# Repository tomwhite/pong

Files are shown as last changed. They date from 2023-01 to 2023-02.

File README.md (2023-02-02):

# Pong

An Arduino port of [pypaddle](https://github.com/arpruss/pypaddle), which is "a paddle ball bouncing game very similar to Pong".

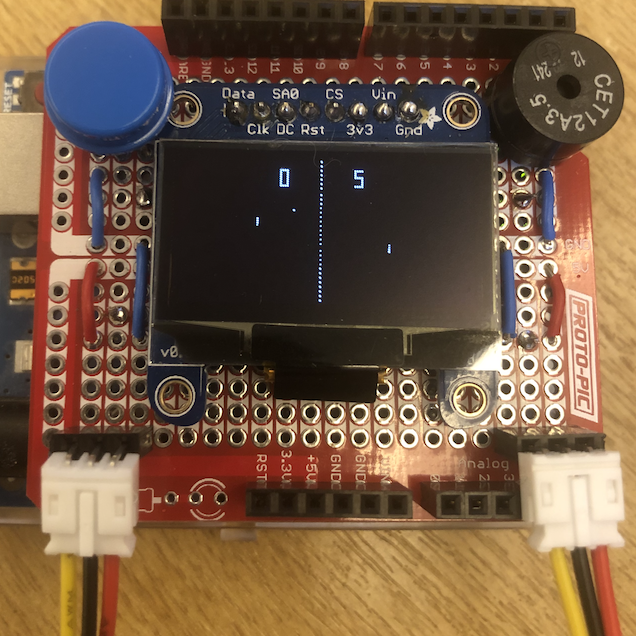
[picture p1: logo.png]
Pong OLED


This version can use an OLED display, or a TV via the TVout library.

## Background

I was inspired to build an Arduino OLED version of Pong after reading [this post by Benjamin Woehrl](https://medium.com/@ruction/arduino-pong-i2c-oled-128x64-bd4185970b50).

After I built it, I came across this [project for building paddle game controllers](https://www.instructables.com/USB-Paddle-Game-Controller/). The author, arpruss, wrote a Python (pygame) implementation of Pong that used the controllers he'd made, and which went to great lengths to reproduce the timings and behaviour of the original. His source for these details included an incredibly in-depth [circuit analysis of the original Atari Pong game](http://www.pong-story.com/LAWN_TENNIS.pdf), by Dr. H. Holden. Before I saw this I hadn't realised that Pong was implemented using TTL chips, rather than a microprocessor.

The code here is a port of the pypaddle pygame implementation to C++ suitable for running on an Arduino. The original pypaddle code is written so that it can scale to different screen sizes, and the timing code is independent of the speed of the update loop, which means that the experience of playing it on a regular machine using pypaddle, or the port on an Arduino with an OLED screen or a TV is virtually indistinguishable.

I also stumbled across this amazing [electronic circuit simulator in Javascript](http://falstad.com/circuit/). I encourage you to have a look at all the examples, but the [Pong simulation](https://www.falstad.com/pong/) is something else. You can even [play a limited form of the game in the browser](https://www.falstad.com/pong/vonly.html)!

## OLED version

### Parts list

- 1x Arduino Uno and power supply
- 1x Mini breadboard
- 1x Adafruit Monochrome 1.3" 128x64 OLED graphic display
- 2x Rotary potentiometer 10kΩ (e.g. Pimoroni NH00N2CB10K)
- 2x Knob
- 1x Push button
- 1x Buzzer - 5V
- 2x JST-PH Jumper Assembly (3 Wire)
- Jumper wires
- Solid core wire
- Solder
- (Optional) 1x Proto shield or Breadboard shield (e.g. Proto-PIC PPBBSFAR3)

### Wiring

Here's the first version I built on a breadboard:

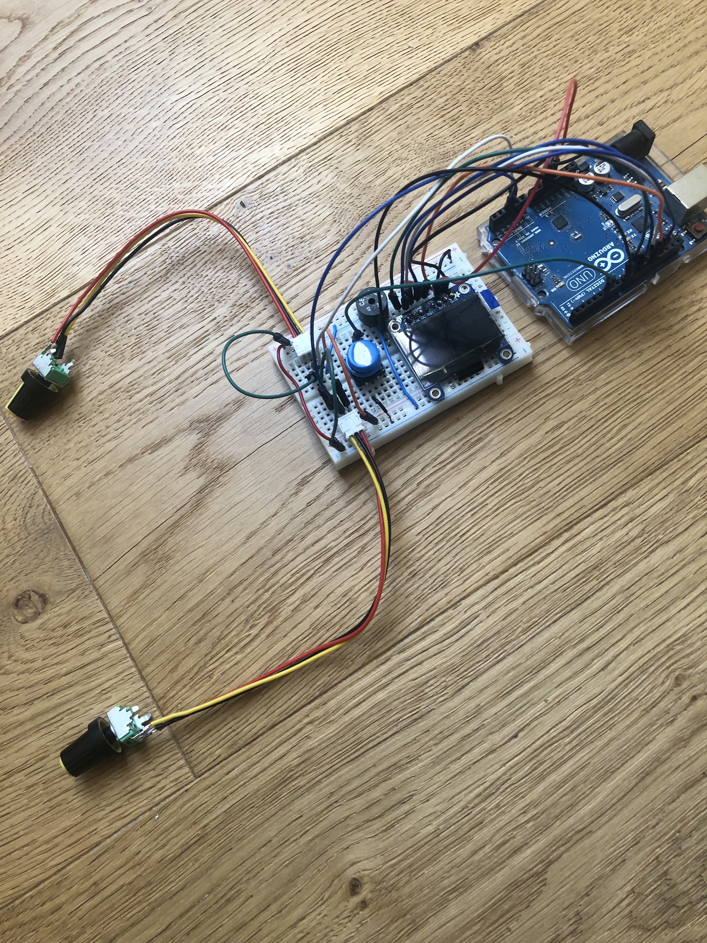
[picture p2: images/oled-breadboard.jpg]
Pong OLED on a breadboard


The controllers are just potentiometers soldered to a JST-PH connector to make it easy to detach them from the breadboard or proto shield.

I used the SPI interface to the OLED, this is explained in detail in the [Adafruit documentation](https://learn.adafruit.com/monochrome-oled-breakouts/wiring-128x64-oleds).

Here's the breadboard wiring diagram:

<!-- ![Breadboard wiring diagram for Pong OLED](images/pong-oled_bb.png | width=500) -->
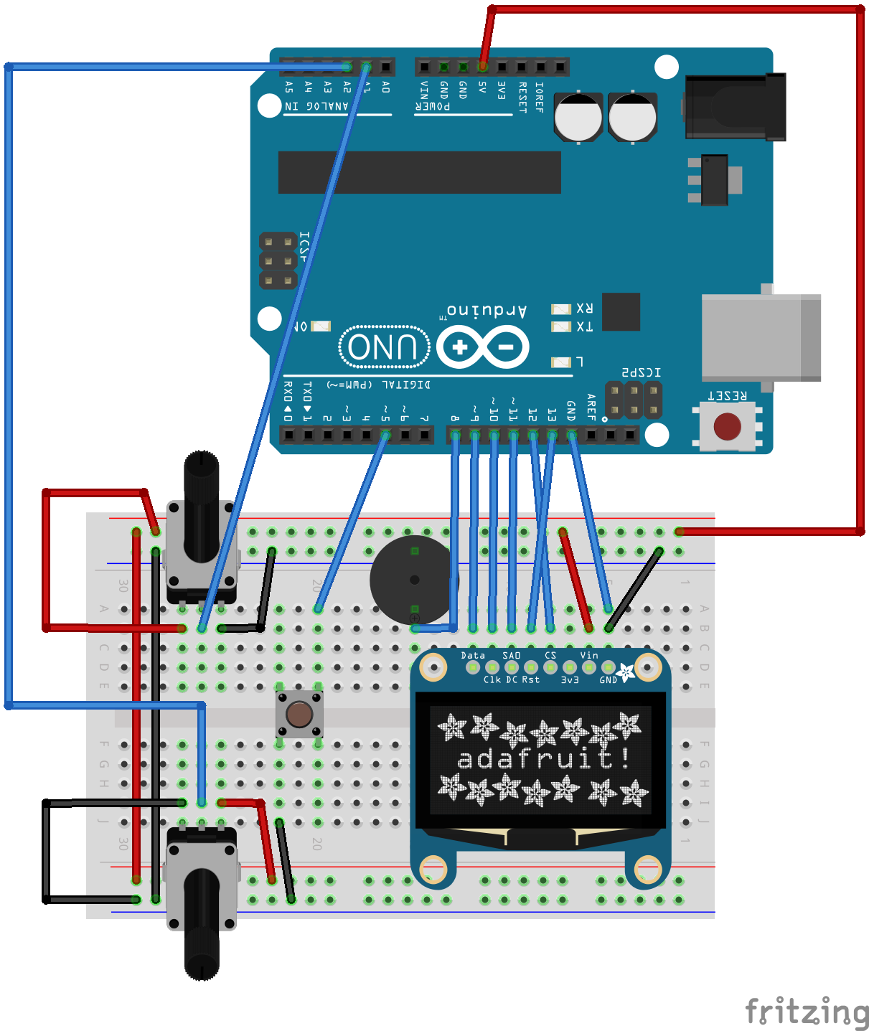
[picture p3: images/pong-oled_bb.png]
Breadboard wiring diagram for Pong OLED


I then transferred the circuit to a proto shield. This is much more compact, and makes it easier to play since the controllers are now either side of the screen.

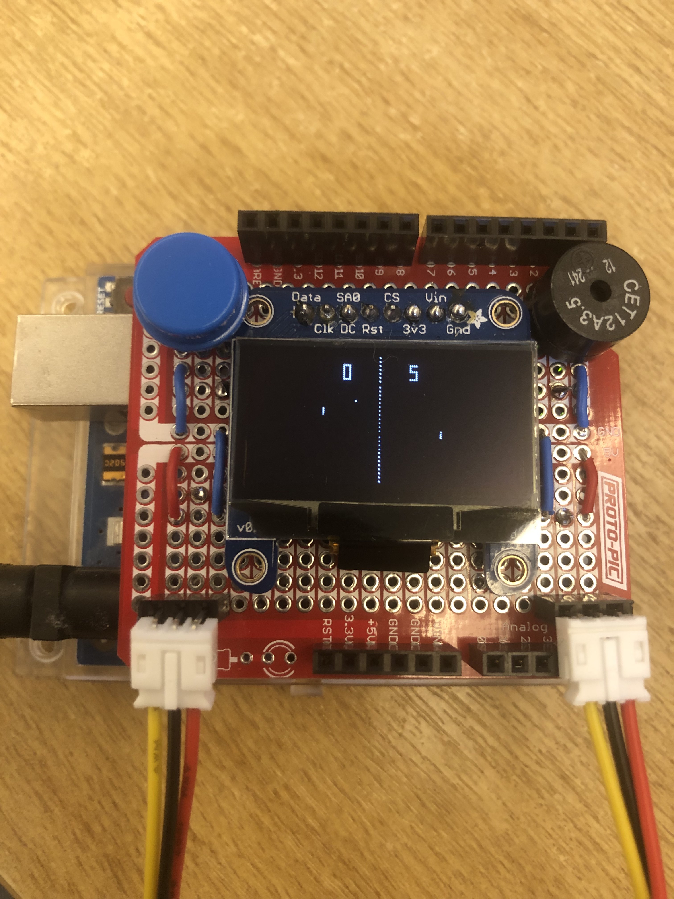
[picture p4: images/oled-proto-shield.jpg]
Pong OLED on a proto shield


## TVout version

After I got the OLED version working, I updated the code so it could work using the TVout library. Since the picture stored in memory is 128x96 pixels (black or white), that's 12,288 bits, or 1,536 bytes. The Arduino Uno only has 2K of SRAM, so that's less than half a kilobyte left for the game itself. To get it to fit I had to use program memory for the digit segment data. (The [Arduino Memory Guide](https://docs.arduino.cc/learn/programming/memory-guide) is well worth a read to understand the different types of memory an Arduino has.)

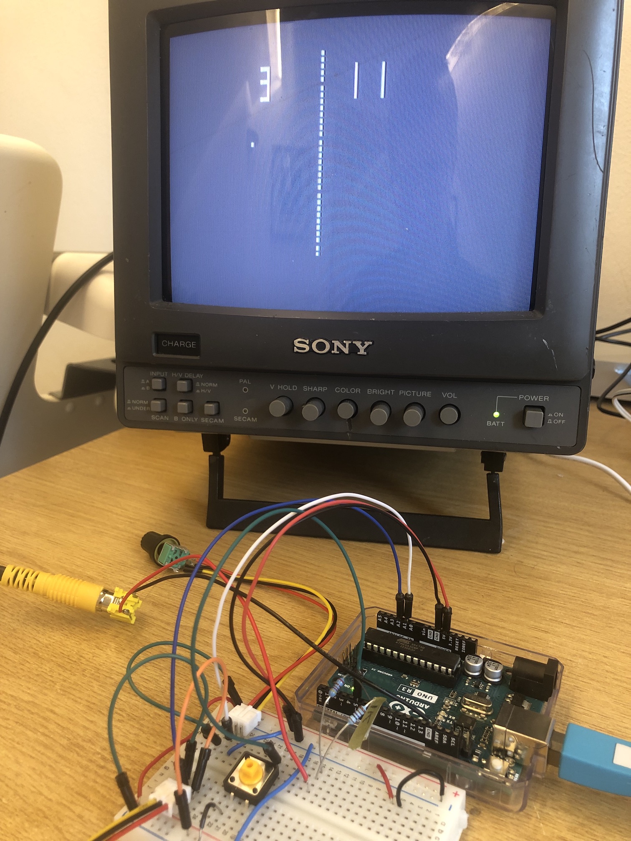
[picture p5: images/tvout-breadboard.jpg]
Pong TVout on a breadboard


Amazingly the TVout library just needs a couple of resistors and a connector to hook up to a TV.

### Parts list

The parts list is not very different from the OLED version. Instead of the OLED graphic display I used a TV with a composite video input, and the following parts.

- 1x Resistor, 470Ω
- 1x Resistor, 1kΩ
- 1x RCA/Phono jack socket
- 1x Composite video cable

For the RCA socket I de-soldered one from a very old broken Raspberry Pi board I had lying around.

### Wiring

Here's the breadboard wiring diagram:

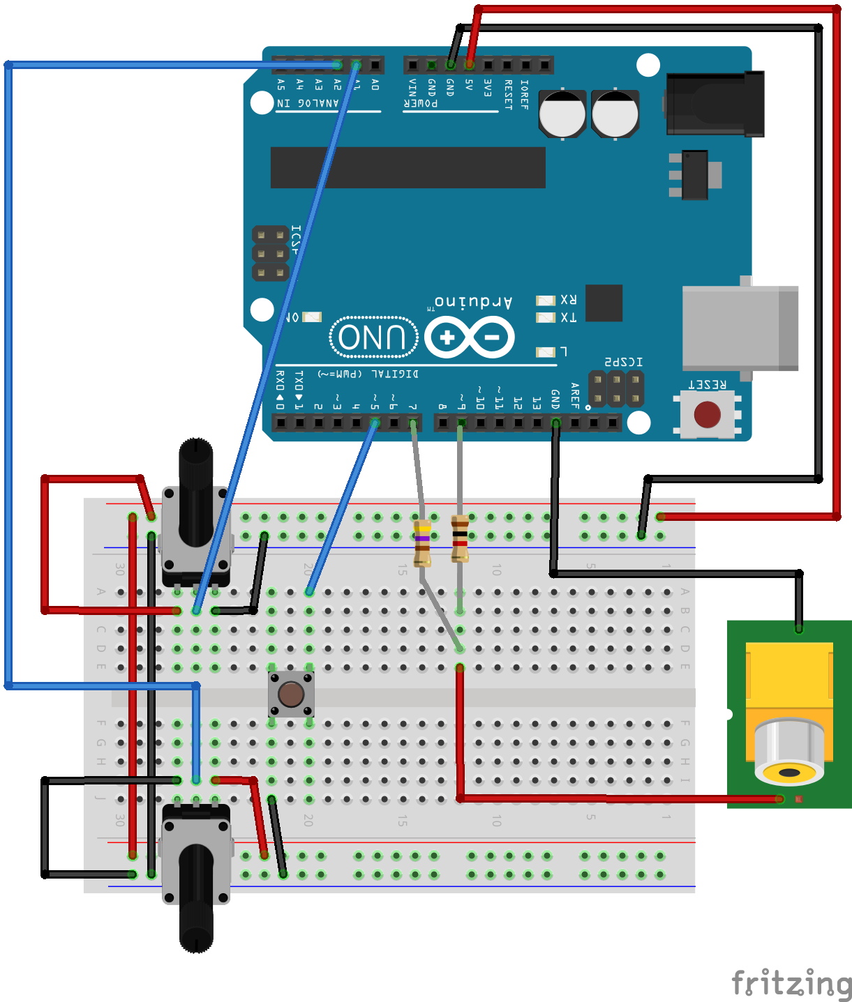
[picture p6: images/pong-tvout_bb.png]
Breadboard wiring diagram for Pong TVout


## Code

Both the OLED and TVout version use the same codebase. You just need to change a `#define` at the top to compile for one or the other.

[pong.ino](pong.ino)

I used version 2.3.1 of the Adafruit SSD1306 library for the OLED display.

There are several versions and forks of the TVout library. I manually installed the one from https://github.com/nootropicdesign/arduino-tvout, from the people behind the wonderful [Hackvision](https://nootropicdesign.com/hackvision/) (which, BTW, also has an implementation of Pong).

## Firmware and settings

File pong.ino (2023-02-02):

/*

  An Arduino port of pypaddle, which is "a paddle ball bouncing game very similar to Pong".

  See https://github.com/arpruss/pypaddle

  This version can use an OLED display, or a TV via the TVout library.

  Further details, including wiring, at https://github.com/tomwhite/pong.

*/

// Compile for an OLED disply by default. To use TVout, comment out the following line.
#define OLED 1

#define CONTROLLER_1 1
#define CONTROLLER_2 2
#define BUTTON_PIN 5
#define SOUND_PIN 8

#ifdef OLED

#include <Adafruit_SSD1306.h>      // Driver library for 'monochrome' 128x64 and 128x32 OLEDs

#define SCREEN_WIDTH 128 // OLED display width, in pixels
#define SCREEN_HEIGHT 64 // OLED display height, in pixels

// Declaration for SSD1306 display connected using software SPI (default case):
#define OLED_MOSI   9
#define OLED_CLK   10
#define OLED_DC    11
#define OLED_CS    12
#define OLED_RESET 13
Adafruit_SSD1306 display(SCREEN_WIDTH, SCREEN_HEIGHT,
                         OLED_MOSI, OLED_CLK, OLED_DC, OLED_RESET, OLED_CS);

void initDisplay() {
  display.begin(SSD1306_SWITCHCAPVCC, 0x3C);  // initialize with the I2C addr 0x3C (for the 128x64)
  display.clearDisplay();
}

void drawRect(byte x0, byte y0, byte w, byte h, char fc) {
  display.drawRect(x0, y0, w, h, fc);
}

void updateDisplay() {
  display.display();
  display.clearDisplay();
}

void playSound(unsigned int frequency, unsigned long duration) {
  tone(SOUND_PIN, frequency, duration);
}

#else

#include <TVout.h>

#define SCREEN_WIDTH 128 // TV display width, in pixels
#define SCREEN_HEIGHT 96 // TV display height, in pixels

TVout TV;

void initDisplay() {
  TV.begin(PAL, 128, 96);
  TV.clear_screen();
}

void drawRect(byte x0, byte y0, byte w, byte h, char fc) {
  TV.draw_rect(x0, y0, w - 1, h - 1, fc);
}

void updateDisplay() {
  TV.delay_frame(1); // avoid flicker
  TV.clear_screen();
}

void playSound(unsigned int frequency, unsigned long duration) {
  TV.tone(frequency, duration);
}


#endif

// Code from here onwards follows the naming and structure of pypaddle as far as possible

const float SERVE_DELAY = 1.5;
const byte HEIGHT = 3;
const float V = 1. / (262 - 16);
const byte WIDTH = 4;
const float H = 1. / (455 - 80);
const float BAT_HEIGHT = 16 * V;
const float BAT_WIDTH = 4 * H;
const float BALL_HEIGHT = 4 * V;
const float BALL_WIDTH = 4 * H;
const float NET_WIDTH = H;
// HSPEEDS in original is represented as two arrays here (HHITS and HSPEEDS)
const byte HHITS[] = { 0, 4, 12 };
const float HSPEEDS[] = { 0.26, 0.39, 0.53 };
const byte VLOADS[] = { 0, 1, 2, 3, 3, 4, 5, 6 };
const float VSPEEDS[] = { 0.680, 0.455, 0.228, 0, -0.226, -0.462, -0.695 };
const float TOP_GAP = 6 * V;
const float BOTTOM_GAP = 4 * V;
const float BAT_1_X_START = 48 * H;
const float NET_X_START = 176 * H;
const float NET_STRIPE_HEIGHT = 4 * V;
const float BAT_2_X_START = 304 * H;
const float BALL_X_START = NET_X_START + 6 * H;
const float SCORE_1_X_START = 48 * H;
const float SCORE_2_X_START = 192 * H;
const float SCORE_Y_START = 16 * V;
const float DIGIT_PIXEL_V = 4 * V;
const float DIGIT_PIXEL_H = 4 * H;
/*
   DIGITS in pypaddle is represented as bit masks rather than strings to save space.
   We also store in program memory, rather than RAM.

   The segments are labelled as follows:

   #A##
   F  B
   #  #
   #G##
   #  #
   E  C
   #  #
   #D##

   Then each digit is encoded as a byte where bits correspond to segments being on or off.

   Digit String   GFE DCBA   Hex
   0     ABCDEF  0011 1111   3F
   1     BC      0000 0110   06
   2     ABGED   0101 1011   5B
   3     ABGCD   0100 1111   4F
   4     FGBC    0110 0110   66
   5     AFGCD   0110 1101   6D
   6     ACDEFG  0111 1101   7D
   7     ABC     0000 0111   07
   8     ABCDEFG 0111 1111   7F
   9     ABCDFG  0110 1111   6F
*/
const byte SEGMENTS[][4] PROGMEM = {{0, 0, 3, 0}, {3, 0, 3, 3}, {3, 3, 3, 7}, {0, 7, 3, 7}, {0, 3, 0, 7}, {0, 0, 0, 3}, {0, 3, 3, 3}};
const byte DIGITS[10] PROGMEM = { 0x3F, 0x06, 0x5B, 0x4F, 0x66, 0x6D, 0x7D, 0x07, 0x7F, 0x6F };

// sounds are separated into two variables (pypaddle uses tuples)
const unsigned int HIT_SOUND_FREQUENCY = 491;
const unsigned long HIT_SOUND_DURATION = 16;
const unsigned int SCORE_SOUND_FREQUENCY = 246;
const unsigned long SCORE_SOUND_DURATION = 220;
const unsigned int BOUNCE_SOUND_FREQUENCY = 246;
const unsigned long BOUNCE_SOUND_DURATION = 16;
const float JOY_RANGE = 0.7;

const boolean SILENT = true;

const byte WINDOW_SIZE[] = { SCREEN_WIDTH, SCREEN_HEIGHT };
const float SCALE[] = { float(WINDOW_SIZE[1]) * WIDTH / HEIGHT, float(WINDOW_SIZE[1]) };
const byte CENTER[] = { WINDOW_SIZE[0] / 2, WINDOW_SIZE[1] / 2 };

float clamp(float x, float m, float M) {
  return max(min(x, M), m);
}

float getHSpeed(int hits) {
  int len = sizeof(HHITS) / sizeof(HHITS[0]);
  float prev = 0;
  for (int i = 0; i < len; i++) {
    if (HHITS[i] > hits) {
      return prev;
    }
    prev = HSPEEDS[i];
  }
  return HSPEEDS[len - 1];
}

float getVSpeedLoad(float y) {
  int len = sizeof(VLOADS) / sizeof(VLOADS[0]);
  int i = int((y + 0.5) * len + 0.5);
  if (i < 0) {
    return VLOADS[0];
  } else if (i >= len) {
    return VLOADS[len - 1];
  } else {
    return VLOADS[i];
  }
}

int sign(float x) {
  if (x < 0) {
    return -1;
  } else if (x > 0) {
    return 1;
  } else {
    return 0;
  }
}

// https://forum.arduino.cc/t/returning-two-values-from-a-function/90068/13
void toScreenXY(float x, float y, int & sx, int & sy) {
  sx = int(0.5 + SCALE[0] * (x - 0.5) + CENTER[0]);
  sy = int(0.5 + SCALE[1] * (y - 0.5) + CENTER[1]);
}

void toScreenWH(float w, float h, int & sw, int & sh) {
  sw = int(0.5 + SCALE[0] * w);
  sw = max(sw, 1);
  sh = int(0.5 + SCALE[1] * h);
  sh = max(sh, 1);
}

class RectSprite {
  protected:
    float _w;
    float _h;
    float _x;
    float _y;
    // velocity components moved to Ball

  public:
    RectSprite(float w, float h, float x, float y) {
      _w = w;
      _h = h;
      _x = x;
      _y = y;
    }

    // pos is y position of hit normalized over self
    boolean hit(RectSprite* target, float & pos) {
      if (abs(_x - target->_x) >= (_w + target->_w) * 0.5) {
        return false;
      } else if (abs(_y - target->_y) >= (_h + target->_h) * 0.5) {
        return false;
      }
      pos =  (_y - target->_y) / _h;
      return true;
    }

    void draw() {
      int sx, sy, sw, sh;
      toScreenXY(_x, _y, sx, sy);
      toScreenWH(_w, _h, sw, sh);
      drawRect(sx, sy, sw, sh, WHITE);
    }
};

class Bat : public RectSprite {
  public:
    byte _index;
    char _direction;

  public:
    Bat(byte index) : RectSprite(BAT_WIDTH, BAT_HEIGHT, 0.5, 0.5) {
      _index = index;
      _direction = (index == 0 ? 1 : -1);
      _x = (index == 0 ? BAT_1_X_START : BAT_2_X_START) + _w * 0.5;
    }

    void setPosition(float offset) {
      _y = (1. - TOP_GAP - BOTTOM_GAP - _h) * 0.5 * (offset + 1) + TOP_GAP + 0.5 * _h;
    }
};

boolean bats = false; // whether bats are active or not
Bat bat0 = Bat(0);
Bat bat1 = Bat(1);

class Ball : public RectSprite {
    float _vx;
    float _vy;
    byte _hits;
    char _serve_direction;
    float _minY;
    float _maxY;
    float _minX;
    float _maxX;
    float _wait;
    byte _load;

  public:
    Ball() : RectSprite(BALL_WIDTH, BALL_HEIGHT, 0.4, 0.) {
      byte load = 0;
      char direction = 1;
      _hits = 0;
      _vx = direction * getHSpeed(_hits);
      _vy = 0.;
      _minY = _h * 0.5;
      _maxY = 1 - _h * 0.5;
      _minX = _w * 0.5;
      _maxX = 1 - _w * 0.5;
      _serve_direction = 0;
      _wait = 0;
      setLoad(load);
    }

    void setLoad(int load) {
      _load = load;
      _vy = VSPEEDS[load];
    }

    void draw() {
      if (_wait <= 0) {
        RectSprite :: draw();
      }
    }

    void serve() {
      _wait = SERVE_DELAY;
    }

    void reverseVertical() {
      int len = sizeof(VLOADS) / sizeof(VLOADS[0]);
      setLoad(VLOADS[len - 1] - _load);
    }

    int updateXY(float dt) {
      if (_wait > 0) {
        _wait -= dt;
        if (_wait <= 0) {
          _x = BALL_X_START - 0.5 * _w;
          if (_serve_direction == 0) {
            _serve_direction = sign(_vx);
          }
          _hits = 0;
          _vx = _serve_direction * getHSpeed(_hits);
        }
      }

      _x += dt * _vx;
      _y += dt * _vy;

      if (_y > _maxY) {
        _y = clamp(_maxY * 2 - _y, _minY, _maxY);
        reverseVertical();
        sound(BOUNCE_SOUND_FREQUENCY, BOUNCE_SOUND_DURATION);
      } else if (_y < _minY) {
        _y = clamp(_minY * 2 - _y, _minY, _maxY);
        reverseVertical();
        sound(BOUNCE_SOUND_FREQUENCY, BOUNCE_SOUND_DURATION);
      }

      if (_wait <= 0) {
        if (bats) {
          float y;
          if (bat0.hit(this, y)) {
            sound(HIT_SOUND_FREQUENCY, HIT_SOUND_DURATION);
            _hits += 1;
            _vx = bat0._direction * getHSpeed(_hits);
            setLoad(getVSpeedLoad(y));
          }
          if (bat1.hit(this, y)) {
            sound(HIT_SOUND_FREQUENCY, HIT_SOUND_DURATION);
            _hits += 1;
            _vx = bat1._direction * getHSpeed(_hits);
            setLoad(getVSpeedLoad(y));
          }
        }
      }

      if (_x < _minX) {
        _vx = abs(_vx);
        _x = _minX;
        if (bats && _wait <= 0) {
          // right scores
          _serve_direction = -1;
          _wait = SERVE_DELAY;
          return 1;
        }
      } else if (_x > _maxX) {
        _vx = -abs(_vx);
        _x = _maxX;
        if (bats && _wait <= 0) {
          // left scores
          _serve_direction = 1;
          _wait = SERVE_DELAY;
          return 0;
        }
      }
      return -1;
    }

};

void drawDigit(float x, float y, int n) {
  int x_, y_;
  toScreenXY(x, y, x_, y_);
  int w, h;
  toScreenWH(DIGIT_PIXEL_H, DIGIT_PIXEL_V, w, h);
  byte d = pgm_read_byte(&(DIGITS[n]));
  for (int i = 0; i <= 7; i++) {
    if (bitRead(d, i)) {
      int sw = (pgm_read_byte(&(SEGMENTS[i][2])) - pgm_read_byte(&(SEGMENTS[i][0])) + 1) * w;
      int sh = (pgm_read_byte(&(SEGMENTS[i][3])) - pgm_read_byte(&(SEGMENTS[i][1])) + 1) * h;
      int sx = x_ + pgm_read_byte(&(SEGMENTS[i][0])) * w;
      int sy = y_ + pgm_read_byte(&(SEGMENTS[i][1])) * h;
      drawRect(sx, sy, sw, sh, WHITE);
    }
  }
}

void drawScore(float x, float y, int score) {
  float x_ = x + DIGIT_PIXEL_H * 4 * 3;
  while (1) {
    drawDigit(x_, y, score % 10);
    score = score / 10;
    if (score == 0) {
      break;
    }
    x_ -= DIGIT_PIXEL_H * 8;
  }
}

byte scores[2] = {0, 0};
Ball ball = Ball();

float get_axis(int index) {
  int controllerValue = index == 0 ? analogRead(CONTROLLER_1) : analogRead(CONTROLLER_2);
  return (controllerValue - 512) / 1024.0;
}

float adjustJoystick(float y) {
  y /= JOY_RANGE;
  return clamp(y, -1, 1);
}

void attract() {
  bats = false;
  ball.setLoad(0);
}

void start() {
  bats = true;
  scores[0] = 0;
  scores[1] = 0;
  ball.serve();
}

void net() {
  float y = 0;
  int w, h;
  toScreenWH(NET_WIDTH, NET_STRIPE_HEIGHT, w, h);
  int sx, sy;
  while (y < 1.) {
    toScreenXY(NET_X_START, y, sx, sy);
    drawRect(sx, sy, w, h, WHITE);
    y += 2 * NET_STRIPE_HEIGHT;
  }
}

void drawBoard() {
  net();
}

void sound(unsigned int frequency, unsigned long duration) {
  if (not SILENT) {
    playSound(frequency, duration);
  }
}

unsigned long prev;

void setup() {
  pinMode(BUTTON_PIN, INPUT_PULLUP);

  Serial.begin(9600);

  initDisplay();

  prev = millis();
}

void loop() {
  if (not bats && digitalRead(BUTTON_PIN) == LOW) {
    start();
  }

  unsigned long now = millis();
  float dt = (now - prev) / 1000.0;
  drawBoard();
  drawScore(SCORE_1_X_START, SCORE_Y_START, scores[0]);
  drawScore(SCORE_2_X_START, SCORE_Y_START, scores[1]);
  if (bats) {
    bat0.setPosition(adjustJoystick(get_axis(0)));
    bat1.setPosition(adjustJoystick(get_axis(1)));
  }
  int edge = ball.updateXY(dt);
  ball.draw();
  if (bats) {
    bat0.draw();
    bat1.draw();
  }
  if (edge != -1 && bats) {
    sound(SCORE_SOUND_FREQUENCY, SCORE_SOUND_DURATION);
    scores[edge] += 1;
    if (scores[edge] == 11) {
      attract();
    }
  }
  updateDisplay();

  prev = now;
}

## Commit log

2023-01-27 Wire up sound for TVout (off by default)
2023-01-29 Add README with assembly details for OLED
    [pong-oled.fzz]
2023-02-02 TVout version of pong
    [pong-tvout.fzz]
